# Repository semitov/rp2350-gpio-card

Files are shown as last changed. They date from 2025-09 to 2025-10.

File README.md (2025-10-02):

# rp2350-gpio-card
Expansion Card circuit based on RP2350 for Framework mainboards providing GPIO to the computer. Circuit is based on [Expansion Card template](https://github.com/FrameworkComputer/ExpansionCards) and [RP2350A Minimal board](https://datasheets.raspberrypi.com/rp2350/hardware-design-with-rp2350.pdf). Designed in [KiCad](https://www.kicad.org/). It got produced and assembled. Its fully functional.

## Gallery
* Render of card with Molex 1054440011 (Framework template)
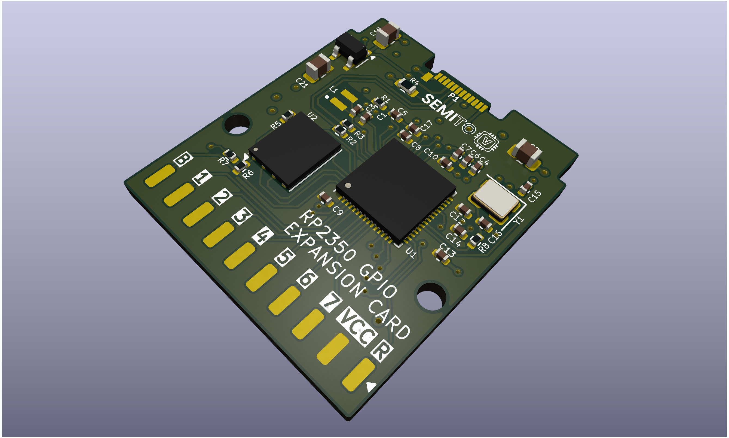
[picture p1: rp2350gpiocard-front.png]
RP2350 GPIO Card prototype render

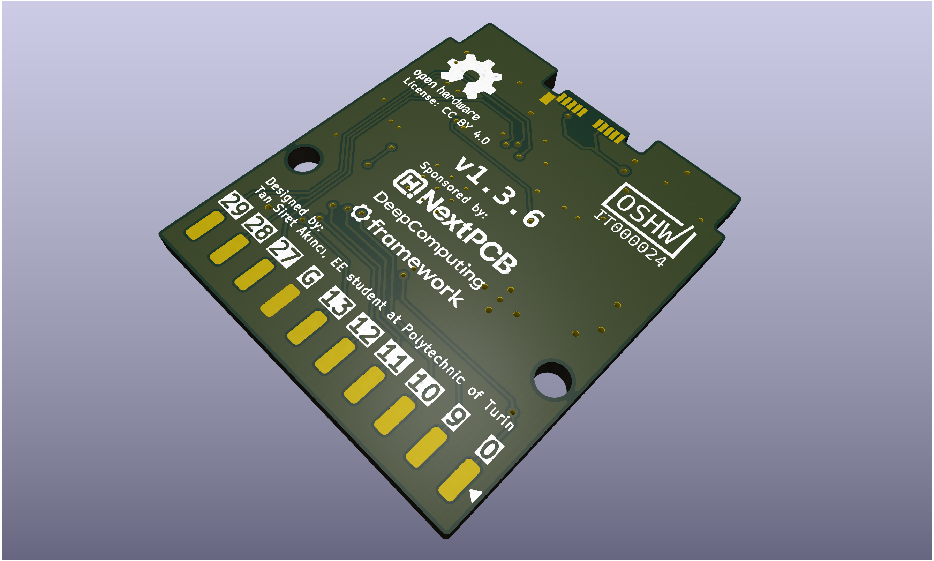
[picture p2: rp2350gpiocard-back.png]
RP2350 GPIO Card prototype render


* Render of card with TYPEC-950-ARP24 (NextPCB template)
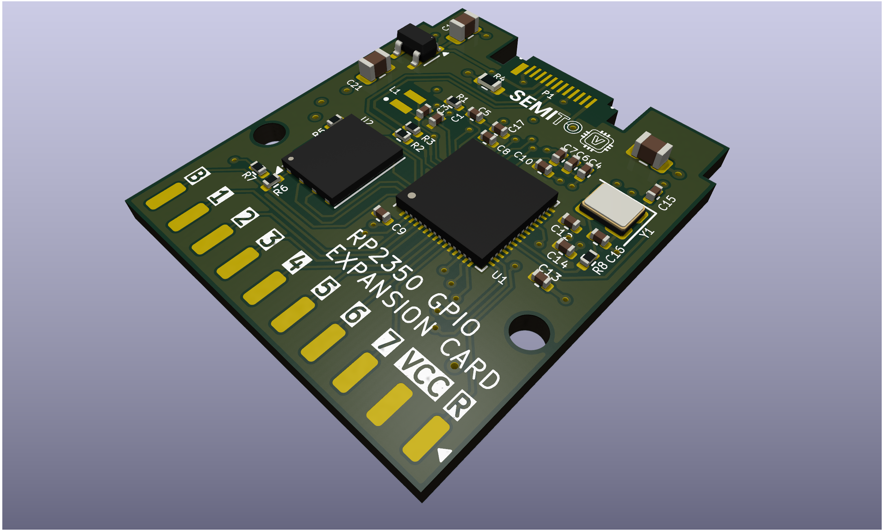
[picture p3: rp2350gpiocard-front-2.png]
RP2350 GPIO Card prototype render

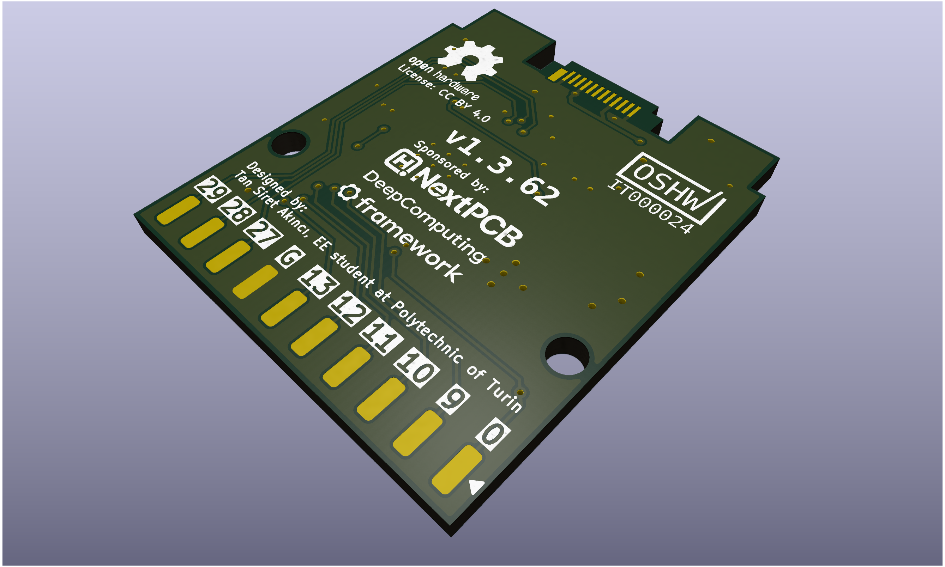
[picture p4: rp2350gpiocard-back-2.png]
RP2350 GPIO Card prototype render


## GPIO
### Front
| Label | Name | SPI | UART | I2C | ADC |
| :---- | :----- | :--- | :--- | :--- | :-- |
| 0 | GPIO0  | SPI0 RX | UART0 TX | I2C0 SDA | |
| 1 | GPIO1  | SPI0 CSn  | UART0 RX | I2C0 SCL | |
| 2 | GPIO2  | SPI0 SCK  | | I2C1 SDA | |
| 3 | GPIO3  | SPI0 TX | | I2C1 SCL | |
| 4 | GPIO4  | SPI0 RX | UART1 TX | I2C0 SDA | |
| 5 | GPIO5  | SPI0 CSn  | UART1 RX | I2C0 SCL | |
| 6 | GPIO6  | SPI0 SCK  | | I2C1 SDA | |
| 7 | GPIO7  | SPI0 TX | | I2C1 SCL | |
| VCC | 3.3v | | | | |
| R | Reset  | | | | |

### Back
| Label | Name | SPI | UART | I2C | ADC |
| :---- | :----- | :--- | :--- | :--- | :---- |
| 29 | GPIO29 | | | | ADC3  |
| 28 | GPIO28 | | | | ADC2  |
| 27 | GPIO27 | | | I2C1 SDL | ADC1  |
| G | Ground | | | | |
| 13 | GPIO13 | SPI1 CSN  | UART0 RX | I2C0 SCL | |
| 12 | GPIO12 | SPI1 RX | UART0 TX | I2C0 SDA | |
| 11 | GPIO11 | SPI1 TX | | I2C1 SCL | |
| 10 | GPIO10 | SPI1 SCK  | | I2C1 SDA | |
| 9 | GPIO9  | SPI1 CSn  | UART1 RX | I2C0 SCL | |
| B | Boot | | | | |

## License
Designed by: [Tan Siret Akıncı](https://github.com/tansiret).
Schematics and footprint are licensed with [CC BY 4.0](LICENSE).
Politecnico di Torino name used in this project is © 2025 Politecnico di Torino. The project is sponsored by © 2025 [DeepComputing](https://deepcomputing.io/) and © 2025 [NextPCB](https://www.nextpcb.com/).
The project has been certified by [OSHWA](https://oshwa.org/) as Open Source Hardware (UID: [IT000024](https://certification.oshwa.org/it000024.html)).
</br>
<a href="https://certification.oshwa.org/it000024.html">
   
</a>

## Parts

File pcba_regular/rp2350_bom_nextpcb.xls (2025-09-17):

Designator* | Quantity* | Manufacturer Part Number* | Manufacturer | Package/Footprint | Description | Procurement Type | Customer Note
C1,C3 | 2 | CL05A475MP5NRNC | Samsung Electro-Mechanics | C_0402_1005Metric_small_pads | 4.7u
C5,C6 | 2 | CL05A475MP5NRNC | Samsung Electro-Mechanics | C_0402_1005Metric | 4.7u
C9,C10,C17,C8,C12,C4,C7,C13,C14 | 9 | CL05B104KO5NNNC | Samsung Electro-Mechanics | C_0402_1005Metric | 100n
C15,C16 | 2 | CL05C150JB5NNNC | Samsung Electro-Mechanics | C_0402_1005Metric | 15p
C19,C2,C21 | 3 | CL21A106KAYNNNE | Samsung Electro-Mechanics | C_0805_2012Metric | 10u
H1,H2 | 2 |  |  | MountingHole_2.2mm_M2 | MountingHole | DNP
J2,J1 | 2 | DNP ! DO NOT PLACE |  |  |  | DNP
L1 | 1 | AOTA-B201610S3R3-101-T | ABRACON | L_pol_2016 | 3.3u
P1 | 1 | USB2.0-AB06 | Panasonic | USB_C_Plug_Molex_105444 | USB_C_Plug_USB2.0
R1 | 1 | RC0402FR-0733RL | YAGEO | R_0402_1005Metric | 33
R3,R2 | 2 | RC0402FR-0727RL | YAGEO | R_0402_1005Metric | 27
R4 | 1 | 0603WAF5101T5E | UNI-ROYAL | R_0603_1608Metric | 5.1k
R5,R7 | 2 |  |  | R_0402_1005Metric | DNF | DNP
R6 | 1 | 0402WGF0000TCE | UNI-ROYAL | R_0402_1005Metric | 0
R8 | 1 | 0402WGF1001TCE | UNI-ROYAL | R_0402_1005Metric | 1k
U1 | 1 | RP2350A | Raspberry Pi | RP2350-QFN-60-1EP_7x7_P0.4mm_EP3.4x3.4mm_ThermalVias | RP2350_60QFN
U2 | 1 | W25Q128JVPIQ | Winbond Electronics | WSON-8-EP(5x6) | W25Q128JVPIQ
U4 | 1 | AP2127K-1.8TRG1 | Diodes | SOT-23-5 | AP2127K-3.3
Y1 | 1 | ABM8-272-T3 | ABRACON | Crystal_SMD_3225-4Pin_3.2x2.5mm | ABM8-272-T3

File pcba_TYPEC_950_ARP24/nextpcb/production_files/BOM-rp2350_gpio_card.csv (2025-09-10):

MPN | Qty | Designator | value | manufacturer | Category | SKU | Customer Supply | Customer Remark
06036D475MAT2A | 2 | C1,C3 | 4.7u | Kyocera | Ceramic Capacitors | -
06036D475MAT2A | 2 | C5,C6 | 4.7u | Kyocera | Ceramic Capacitors | -
06035L104K4T2A | 9 | C9,C10,C17,C8,C12,C4,C7,C13,C14 | 100n | Kyocera | Ceramic Capacitors | 1009753559
VJ0603A150JXBAP | 2 | C15,C16 | 15p | Vishay | Ceramic Capacitors | -
UMK325BJ106KM-T | 3 | C19,C2,C21 | 10u | Taiyo Yuden | Ceramic Capacitors | 2500324717
 | 2 | H1,H2 | MountingHole
4610X-101-561LF | 2 | J2,J1 | Conn_01x10_Pin | Bourns | Resistor Arrays | -
B32926C3335M000 | 1 | L1 | 3.3u | TDK | Capacitors | -
USB2.0-AB06 | 1 | P1 | USB_C_Plug_USB2.0 | Panasonic | Tools and Supplies | -
XF2M-3315-1A | 1 | R1 | 33 | Omron | FFC / FPC | 1027849864
2-84953-7 | 2 | R3,R2 | 27 | TE Connectivity (Tyco Electronics) | FFC / FPC | -
CRCW04025K10JNED | 1 | R4 | 5.1k | Vishay | Chip SMD Resistors | 1007326799
STS4DNF60L | 2 | R5,R7 | DNF | STMicroelectronics | MOSFETs | 1018687185
CR0603-J/-000ELF | 1 | R6 | 0 | Bourns | Chip SMD Resistors | -
CR1206-FX-1001ELF | 1 | R8 | 1k | Bourns | Chip SMD Resistors | 1002726470
 | 1 | U1 | RP2350_60QFN
W25Q128JVSIQ | 1 | U2 | W25Q128JVS | Winbond Electronics | FLASH | 1003909429
AP2127K-1.8TRG1 | 1 | U4 | AP2127K-3.3 | Diodes | Linear Voltage Regulators, LDO | 2500317187
RDE5C1H272J0S1H03A | 1 | Y1 | ABM8-272-T3 | Murata | Ceramic Capacitors | -

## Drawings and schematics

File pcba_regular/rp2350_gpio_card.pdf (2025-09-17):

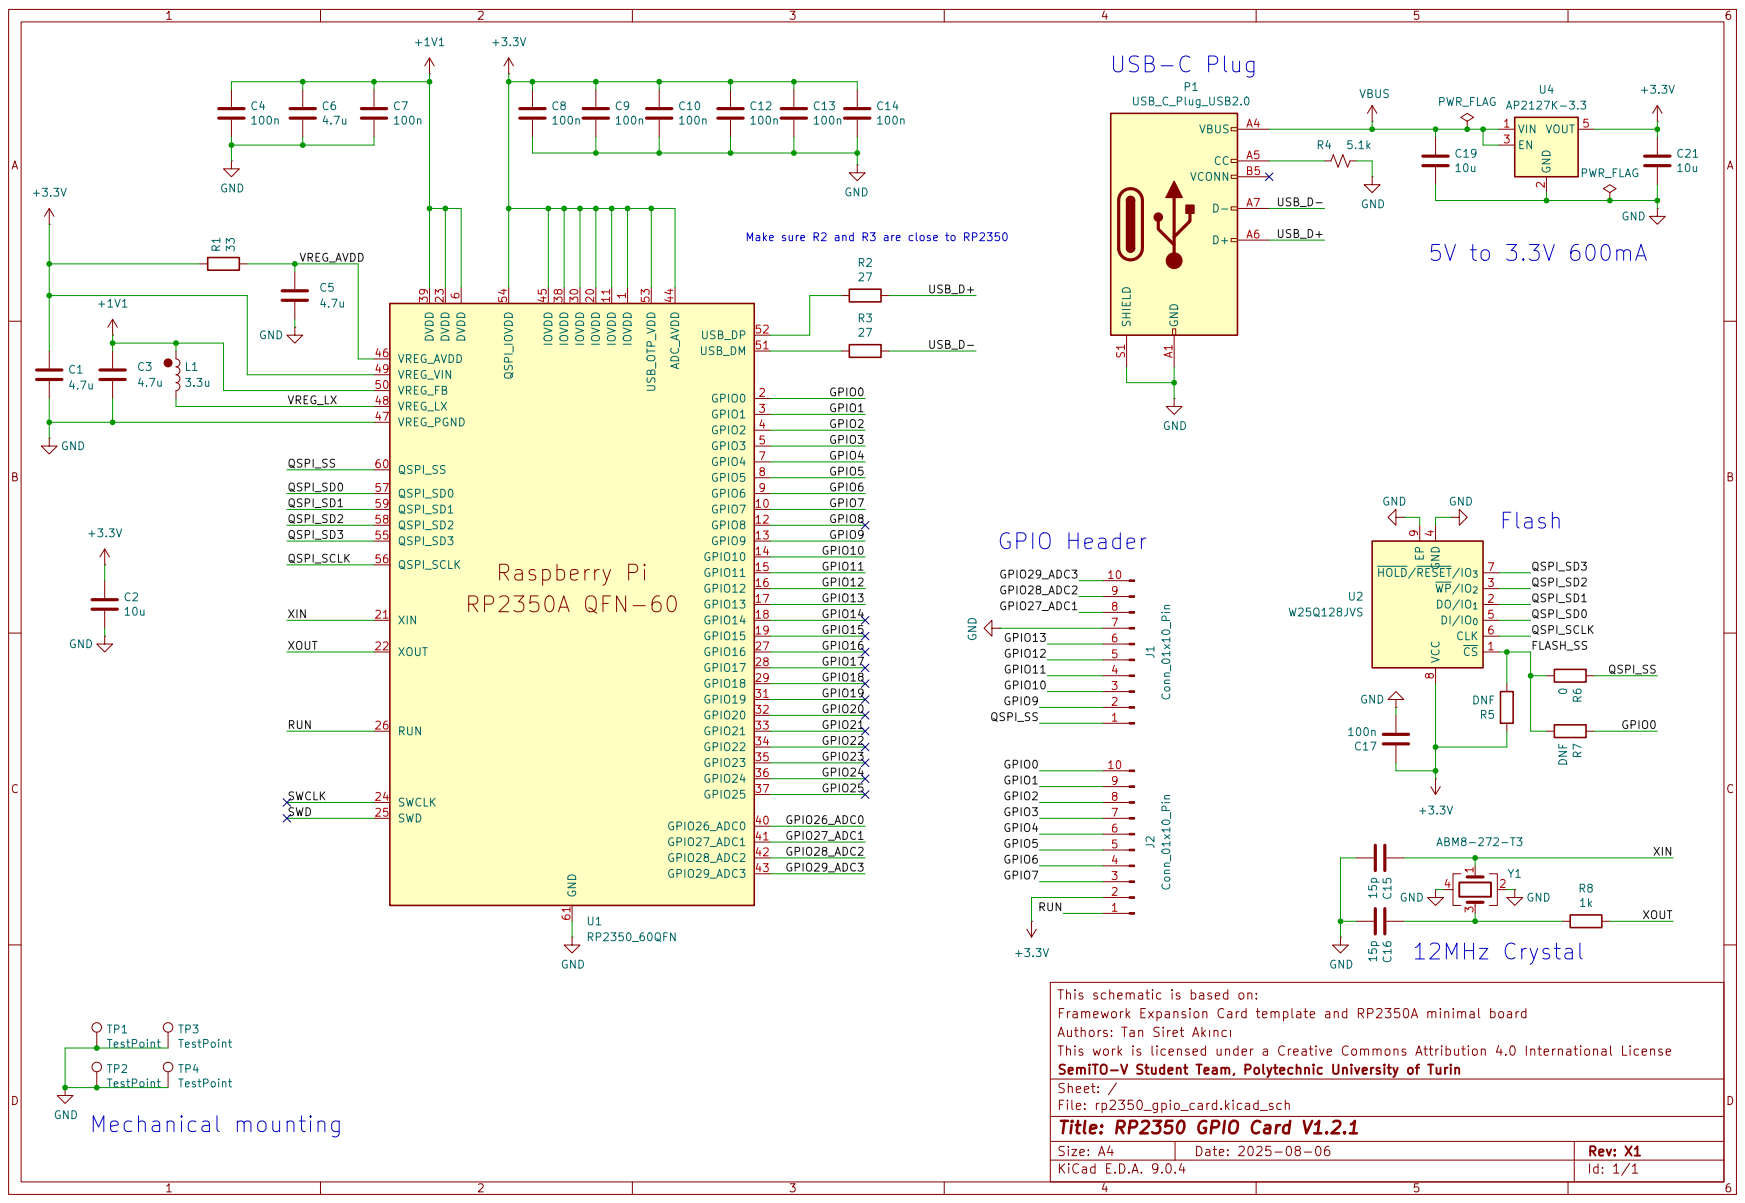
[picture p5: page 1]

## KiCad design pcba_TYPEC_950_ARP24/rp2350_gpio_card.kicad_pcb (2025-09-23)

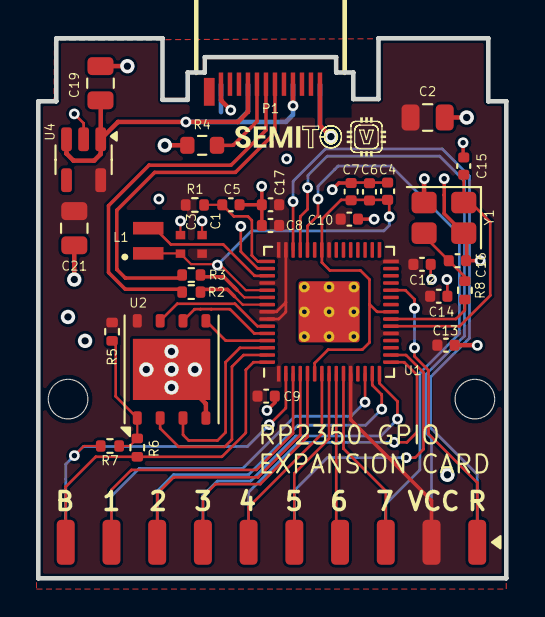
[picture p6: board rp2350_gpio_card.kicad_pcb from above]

Board: 4 copper layers, 26.0 x 30.0 mm, 36 parts (1 on the bottom side), 38 nets.

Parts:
C1, C3: 4.7u; C_0402_1005Metric_small_pads
C2, C19, C21: 10u; C_0805_2012Metric
C4, C7, C8, C9, C10, C12, C13, C14, C17: 100n; C_0402_1005Metric
C5, C6: 4.7u; C_0402_1005Metric
C15, C16: 15p; C_0402_1005Metric
H1, H2: MountingHole; MountingHole_2.2mm_M2
J1, J2: Conn_01x10_Pin; Custom_Harwin_M20-89010xx_1x10_P2.54mm_Horizontal
L1: 3.3u; L_pol_2016
P1: USB_C_Plug_USB2.0; TYPEC-SMD_TYPEC-950-ARP24
R1: 33; R_0402_1005Metric
R2, R3: 27; R_0402_1005Metric
R4: 5.1k; R_0603_1608Metric
R5, R7: DNF; R_0402_1005Metric
R6: 0; R_0402_1005Metric
R8: 1k; R_0402_1005Metric
U1: RP2350_60QFN; RP2350-QFN-60-1EP_7x7_P0.4mm_EP3.4x3.4mm_ThermalVias
U2: W25Q128JVS; WSON-8-1EP_6x5mm_P1.27mm_EP3.4x4.3mm
U4: AP2127K-3.3; SOT-23-5
Y1: ABM8-272-T3; Crystal_SMD_3225-4Pin_3.2x2.5mm

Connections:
+1V1: C3.1, C4.1, C6.1, C7.1, L1.1, U1.6 (DVDD), U1.23 (DVDD), U1.39 (DVDD), U1.50 (VREG_FB)
+3.3V: C1.1, C2.1, C8.1, C9.1, C10.1, C12.1, C13.1, C14.1, C17.1, C21.1, J2.2, R1.1, R5.1, U1.1 (IOVDD), U1.11 (IOVDD), U1.20 (IOVDD), U1.30 (IOVDD), U1.38 (IOVDD), U1.44 (ADC_AVDD), U1.45 (IOVDD), U1.49 (VREG_VIN), U1.53 (USB_OTP_VDD), U1.54 (QSPI_IOVDD), U2.8 (VCC), U4.5 (VOUT)
/FLASH_SS: R5.2, R6.2, R7.2, U2.1 (~CS)
/GPIO0: J1.1, R7.1, U1.2 (GPIO0)
/GPIO1: J2.9, U1.3 (GPIO1)
/GPIO2: J2.8, U1.4 (GPIO2)
/GPIO3: J2.7, U1.5 (GPIO3)
/GPIO4: J2.6, U1.7 (GPIO4)
/GPIO5: J2.5, U1.8 (GPIO5)
/GPIO6: J2.4, U1.9 (GPIO6)
/GPIO7: J2.3, U1.10 (GPIO7)
/GPIO9: J1.2, U1.13 (GPIO9)
/GPIO10: J1.3, U1.14 (GPIO10)
/GPIO11: J1.4, U1.15 (GPIO11)
/GPIO12: J1.5, U1.16 (GPIO12)
/GPIO13: J1.6, U1.17 (GPIO13)
/GPIO27_ADC1: J1.8, U1.41 (GPIO27_ADC1)
/GPIO28_ADC2: J1.9, U1.42 (GPIO28_ADC2)
/GPIO29_ADC3: J1.10, U1.43 (GPIO29_ADC3)
/QSPI_SCLK: U1.56 (QSPI_SCLK), U2.6 (CLK)
/QSPI_SD0: U1.57 (QSPI_SD0), U2.5 (DI/IO_{0})
/QSPI_SD1: U1.59 (QSPI_SD1), U2.2 (DO/IO_{1})
/QSPI_SD2: U1.58 (QSPI_SD2), U2.3 (~WP/IO_{2})
/QSPI_SD3: U1.55 (QSPI_SD3), U2.7 (~HOLD/~RESET/IO_{3})
/QSPI_SS: J2.10, R6.1, U1.60 (QSPI_SS)
/RUN: J2.1, U1.26 (RUN)
/USB_D+: P1.A6 (D+), R2.1
/USB_D-: P1.A7 (D-), R3.1
/VREG_AVDD: C5.1, R1.2, U1.46 (VREG_AVDD)
/VREG_LX: L1.2, U1.48 (VREG_LX)
/XIN: C15.1, U1.21 (XIN), Y1.1
/XOUT: R8.1, U1.22 (XOUT)
GND: C1.2, C2.2, C3.2, C4.2, C5.2, C6.2, C7.2, C8.2, C9.2, C10.2, C12.2, C13.2, C14.2, C15.2, C16.2, C17.2, C19.2, C21.2, J1.7, P1.A1 (GND), P1.A12 (GND), P1.B1 (GND), P1.B12 (GND), R4.2, U1.47 (VREG_PGND), U1.61 (GND), U2.4 (GND), U2.9 (EP), U4.2 (GND), Y1.2, Y1.4
unnamed: C16.1, R8.2, Y1.3
unnamed: P1.A5 (CC), R4.1
unnamed: R3.2, U1.51 (USB_DM)
unnamed: R2.2, U1.52 (USB_DP)
VBUS: C19.1, P1.A4 (VBUS), P1.A9 (VBUS), P1.B4 (VBUS), P1.B9 (VBUS), U4.1 (VIN), U4.3 (EN)

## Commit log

2025-08-04 initial commit with first version of schematics
    [rp2350_gpio_card.kicad_pcb, rp2350_gpio_card.kicad_sch]
2025-08-04 update schematics and start working on pcb (very WIP, need help)
    [rp2350_gpio_card.csv, rp2350_gpio_card.kicad_pcb, rp2350_gpio_card.kicad_sch]
2025-08-06 finish first PCB prototype, modify schematic
    [rp2350_gpio_card.csv, rp2350_gpio_card.kicad_pcb, rp2350_gpio_card.kicad_sch]
2025-08-06 update fillings
    [rp2350_gpio_card.kicad_pcb]
2025-08-06 add silkscreen logos and stuff
    [rp2350_gpio_card.kicad_pcb]
2025-08-06 minor changes
    [rp2350_gpio_card.kicad_pcb, rp2350_gpio_card.kicad_sch]
2025-08-07 change footprint, version v122
    [rp2350_gpio_card.kicad_pcb, rp2350_gpio_card.kicad_sch]
2025-08-07 green pcb
2025-08-10 purple pcb
    [rp2350_gpio_card-B_Cu.gbr, rp2350_gpio_card-B_Silkscreen.gbr, rp2350_gpio_card-Edge_Cuts.gbr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]
2025-08-11 add copyright claim
    [rp2350_gpio_card.kicad_pcb]
2025-08-21 update design
    [bom.csv, designators.csv, positions.csv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]
2025-08-22 version 1.2.4 - fix floating pads and some errors
    [rp2350_gpio_card.kicad_pcb]
2025-08-24 version 1.3.0 - major fixes for floating pins
    [rp2350_gpio_card.kicad_pcb]
2025-08-24 version 1.3.1 - thermal fix, new render
    [rp2350_gpio_card.kicad_pcb]
2025-08-24 edit silkscreen
    [rp2350_gpio_card.kicad_pcb]
2025-08-24 fix all floating errors
    [rp2350_gpio_card.kicad_pcb]
2025-08-24 version v132
    [rp2350_gpio_card.kicad_pcb]
2025-08-24 minor trace edit
    [rp2350_gpio_card.kicad_pcb]
2025-08-24 fix usb connection issues
    [rp2350_gpio_card.kicad_pcb]
2025-08-29 add OSHW certification
    [positions.csv, rp2350_gpio_card.kicad_pcb]
2025-08-29 edit pcb
    [bom.csv, designators.csv, positions.csv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]
2025-09-03 update board, add NextPCB silkscreen, add sponsors to the readme
    [BOM-rp2350_gpio_card.csv, bom.csv, designators.csv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]
2025-09-09 minor touches
    [BOM-rp2350_gpio_card.csv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]
2025-09-09 fix inductor magnetism issue and rearrange several other components according to RP2350 datasheet
    [BOM_rp2350_gpio_card.csv, rp2350_gpio_card.csv, rp2350_gpio_card.kicad_pcb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]
2025-09-10 2 layer gerber and minor fix
    [BOM-rp2350_gpio_card.csv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]
2025-09-10 add no fill zone to L1
    [rp2350_gpio_card-B_Cu.gbr, rp2350_gpio_card-B_Silkscreen.gbr, rp2350_gpio_card-Edge_Cuts.gbr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]
2025-09-11 version 1.3.5 - fix impedance mismatch at usb and improve design
    [rp2350_gpio_card.kicad_pcb]
2025-09-11 small silkscreen edit
    [rp2350_gpio_card-B_Cu.gbr, rp2350_gpio_card-B_Silkscreen.gbr, rp2350_gpio_card-Edge_Cuts.gbr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]
2025-09-17 clean up and update BOM/pos files
    [BOM-rp2350_gpio_card.csv, BOM_rp2350_gpio_card.csv, bom.csv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]
2025-09-18 switch to solid connection rather than thermal relief
    [rp2350_gpio_card-CuBottom.gbr, rp2350_gpio_card-CuTop.gbr, rp2350_gpio_card-EdgeCuts.gbr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]
2025-09-18 fix DFM
    [rp2350_gpio_card-CuBottom.gbr, rp2350_gpio_card-CuTop.gbr, rp2350_gpio_card-EdgeCuts.gbr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]
2025-09-19 version 1.3.6 - smaller edge to copper clearance and minor design changes
    [rp2350_gpio_card.kicad_pcb]
2025-09-19 small component placement changes
    [rp2350_gpio_card.kicad_pcb, rp2350_gpio_card.kicad_sch]
2025-09-22 add different type-c version of the board
    [BOM-rp2350_gpio_card.csv, rp2350_bom_nextpcb.xls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]
2025-09-23 minor type-c fix
    [CPL-rp2350_gpio_card.csv, rp2350_gpio_card-CuBottom.gbr, rp2350_gpio_card-CuTop.gbr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]

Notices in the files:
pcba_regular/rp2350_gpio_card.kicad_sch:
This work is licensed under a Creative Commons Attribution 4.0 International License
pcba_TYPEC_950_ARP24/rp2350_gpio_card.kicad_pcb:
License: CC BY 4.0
